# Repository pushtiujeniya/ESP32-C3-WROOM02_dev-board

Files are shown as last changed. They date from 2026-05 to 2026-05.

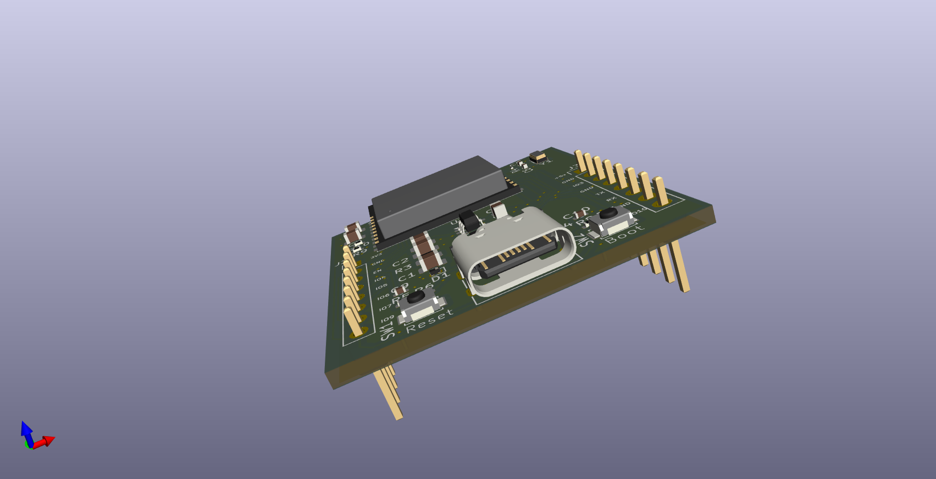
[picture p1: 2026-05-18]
3D view/3D_ USB view.png

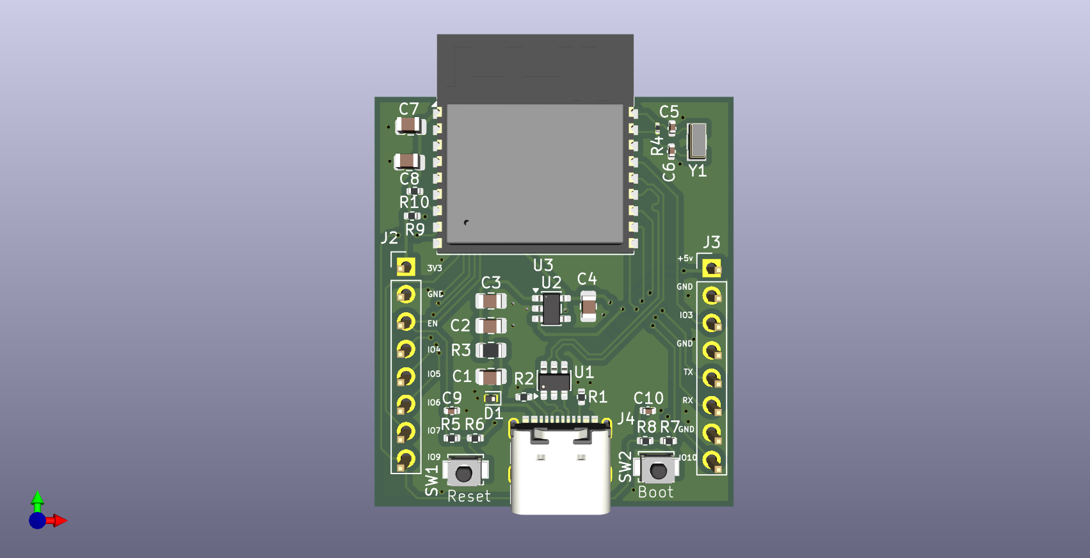
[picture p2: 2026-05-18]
3D view/3D_ Top view.png

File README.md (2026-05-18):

# ESP32-C3-WROOM-02 Development Board

## Overview

This project is a custom 2-layer development board designed around the ESP32-C3-WROOM-02 Wi‑Fi + Bluetooth MCU module. The board includes USB Type‑C power input, onboard 3.3V regulation, boot/reset circuitry, GPIO breakout headers, and USB protection components.

## Features

* ESP32-C3-WROOM-02 module
* USB Type‑C interface
* Onboard 3.3V regulator
* Boot and reset buttons
* GPIO breakout headers
* USB ESD protection
* Power indicator LED
* 2-layer PCB design

## Applications

* IoT devices
* Embedded development
* Sensor interfacing
* Wireless communication projects
* Learning and prototyping

## Hardware Included

* ESP32-C3-WROOM-02 MCU module
* USB Type‑C connector
* Voltage regulator
* Decoupling capacitors
* ESD protection devices
* Boot/reset circuitry
* GPIO expansion headers

## Notes

* Operates on 3.3V logic
* Powered through USB Type‑C
* Suitable for firmware development using ESP-IDF or Arduino framework

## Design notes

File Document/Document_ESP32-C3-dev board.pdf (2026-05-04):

ESP32-C3-WROOM02 mini module development board

Main Hardware components

- USB 2.0 type C connector
- LDO (AP211K-3.3) which converts 3.3V required voltage for power on the MCU
- Boot button- to flash the firmware or to go into bootloader mode to flash the firmware
- Reset button- to reset the MCU manually
- External 32.768KHZ crystal oscillator
- Pin header for JTAG/UART
- ESD protection circuit from USB to LDO to protect the USB data line(USBLC6-2SC6)

Working flow of the board
- USB type C connector will be the main power input to the board
- From USB we get the 5 V DC voltage which goes to LDO which convert the 3.3V with protection circuit in between from 5 V to 3.3V
- 3.3V power rail from LDO will direct goes to the power on to ESP32-C3 mini
- Boot button at (GPIO8) is used to put MCU into programming mode
- Reset button (at EN pin) allows to reset the MCU manually
- External crystal 32.768khz provide stable clock cycle
- Pin header for UART/JTAG for debugging mode

USB C connector

- vbus
Power pin got the 5V power from the PC

Cc1 and cc2 pins
Pins used to detect the connection , cable orientation
By keeping pull up or pull down resistors connection at cc1 nad cc2 the cable detected and decided whether i have to act as host ( to drive the power to the board) or device ( to ask for power from the host)

It is configuration channel pins
This pins tell the host that cable is inserted
So usb plug detection is done by this
By default USB standards the USB type C connecter will get the 5V DC from the host (pc or charger)

How can type c verify the orientation of cable detect
In normal insertion cable connects c1
Cc2 not detected

But in flipped insertion

C2- not detected
C1- cable connects

Only 1 cc1 lines is physically connected at a time other one is floating Host (PC or charger ) checks voltage on both pins
When host checks voltage on both pins
If voltage available on c1= normal orientation
If voltage available on c2= flipped orientation

SBU1 and SBU2 pins
Sideband pins
In normal USB2.0 communication this pins are not used and left unconnected
This pin used when USB c used as headphone jack means when this pins carry some audio data

USBLC6-2SC6

This is ESD protection IC used to protect the data lines from USB connector coming It will protect the data lines from static electricity and voltage spikes

In this 1 and 3 pins are input pins
4 and 5 are output pins
5= vbus
2=gnd

So at 4 and 6 pins getting output USB D+ and USB D- data

LDO (AP2112K-3.3)

This will convert the 5 V which is got from the USB connector and convert it into 3.3v to power on the MCU
As ESP32-C3 module
Ideal current consumption is 20 to 40mA
And active wifi current consumption=300 to 400mA
So decided to have some extra current capacity carrying LDO AP2112K-3.3 this is 600mA current carrying capacity of LDO AMS1117-3.3 the dropout voltage =1.3v max
AP2112K-3.3 the dropout voltage is 400mV
So power loss/heat would be less in AP2112K-3.3
Also it has fast response to sudden current peak

MCU
ESP32-C3-WROOM02

VBUS
MCU operates at 3.3V
3.3V rail is the main power supply provider rail Decoupling capacitor at power line= 10uf and 0.1uf

10uF will filter out low frequency noise
0.1uF will filter out high frequency noise

EPAD pin
This pin should connect with ground pin for good thermal performance

Crystal
MCU has internal crystal oscillator of 40MHz crystal
And internal crystal oscillator (32.768khz) can be connected with IO0 and IO1

EN pin at pin 2
This pin is used to manually boot the MCU for flashing the firmware or go into bootloader mode

To enter into bootloader mode
Hold boot button (GPIO 9 low)
Press reset (EN pin low)
Release reset
Release boot

So manually push button switch is connected to with this pin
And by default in nominal mode the EN pin is high by pull up resistor
and when switch is pressed it connects with gnd and goes to low
When the switch is pressed the EN pin goes low immediately and when released the switch EN pin again goes high so this fast switching can create noise in EN pin
So to remove that noise rise delay is added
By t=RC
There should be resistor and capacitor in series with the other end of the switch
This RC combination circuit is called debouncing circuit
Also one pull up resistor is connected to the switch to keep the by default switch in high mode When it is pressed it goes to gnd

USB pins in MCU
IO18 for USB-D-IO19 for USB-D+

From USB this data lines are connected to MCU io18 and io19 poins
In between from USB to MCU path there is one ESD protection diode which is USBLC6-CS and output of this diode is goes into MCU data lines pins

Strapping pins
This pins are used to decide MCU operating mode (normal flashing mode or bootloader mode) GPIO2, GPIO8, GPIO9 are for strapping pins
While power on time the MCU checks this strapping pins at that time if pins are high then MCU run into normal mode so it will run the flashed firmware
But if GPIO8, GPIO9 are low= run into bootloader mode
To keep the strapping pins high for normal mode 10kohm pull up resistors are required

TX, RX pins of the MCU

IO20 and IO21 are the TX and RX pins IO20- RX
IO21-TX

Crystal connection with MCU
There are 2 load capacitors required with external crystal to stabilize the oscillation And one resistor to help oscillations start easily

Load capacitors are used to stabilize the oscillations.
Load capacitors values are mentioned in the datasheet of crystal oscillator

COMPONENT SELECTION and TECHNICAL SPECIFICATION

USB section

At cc1 and cc2 pins there is 5.1kohm pull down resistors
This pull down resistors used to tell the host that i am the device give me power through USB connector
5.1kohm value this is mentioned in the type c specification

Here why pull down resistors connected what if i connect pull up resistors
If pull up resistors connected at cc1 and cc1 it mean usb will drive the power (it would become host)
So in case when you want to give the power to the board by USB supply then connect pull up resistors at cc1 and cc2 pins

By pull down resistors connection at cc1 and cc2 = i am the device give me the power supply Asking for power from the host

LDO decoupling capacitors

At vin and vout pin there is decoupling capacitors needed to remove high frequency noise and low frequency noise
Here 4.7uF used
1uf to 4.7uf value range= to remove low frequency noise
0.1uf= to remove high frequency noise

In datasheet 1uF is mentioned for vin and vout
We can use 4.7uf also

BOOT SWITCH AND RESET SWITCH
As the by default the boot and reset switch need to keep at high state so that whenever user want to enter into boot mode by pressing the switch you can do it

So pull up resistors required to keep the switch by default in high state
Note: should keep low value for pull up resistors in the switch so that by weak enough the pin easily goes to low when button is pressed

Here 10kohm is enough to keep the line low

Debounce circuit ( R and C) value at switch R=10kohm
C=0.1uf

t=RC= 10kohm x 0.1uf =1ms
This will add 1ms of time delay in rise of the EN or reset pin because if it goes immediately high after pressing the switch then noise might be added
This combination of the RC at switch is called debounce circuit

WHY EXTERNAL CRYSTALS NEEDED WHEN MCU HAS INTERNAL CRYSTAL ENOUGH

When internal crystal lacks at stability, precision then external l crystal is used

Both load capacitors have same value at crystal connection
And one resistor in parallel

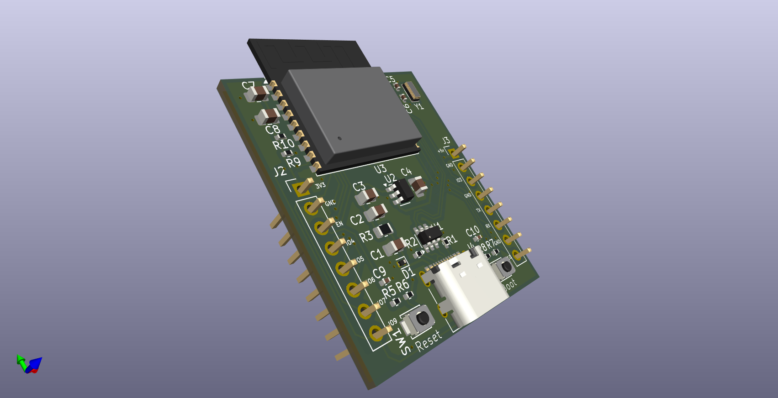
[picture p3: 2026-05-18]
3D view/3D_side view.png

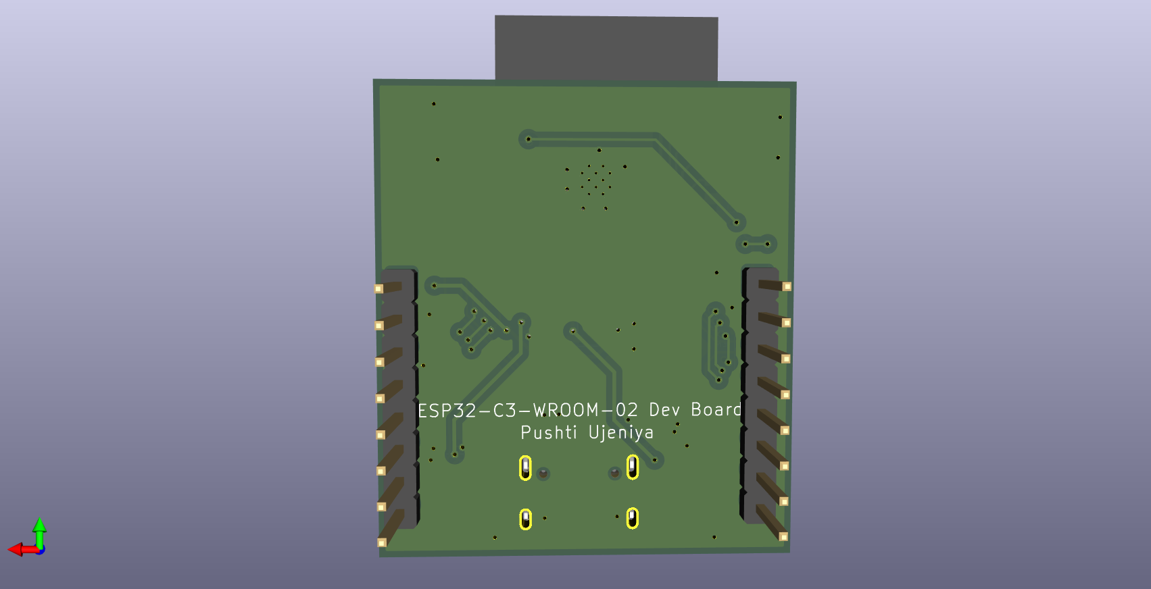
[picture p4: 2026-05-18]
3D view/3D_Bottom view.png

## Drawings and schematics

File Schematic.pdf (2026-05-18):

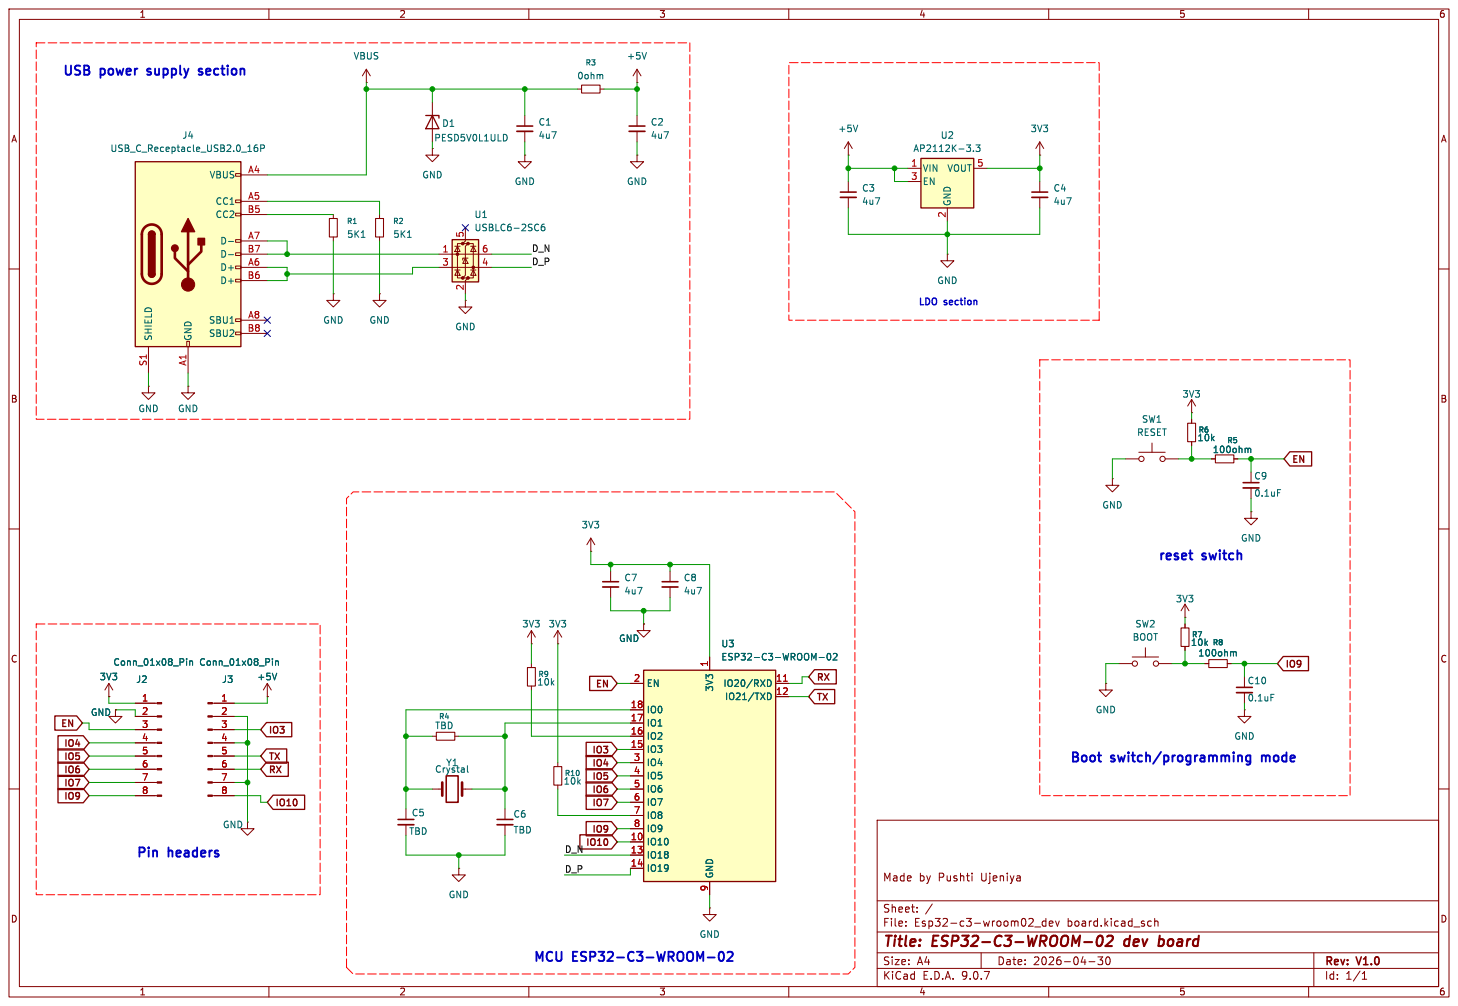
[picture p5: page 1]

USB power supply section

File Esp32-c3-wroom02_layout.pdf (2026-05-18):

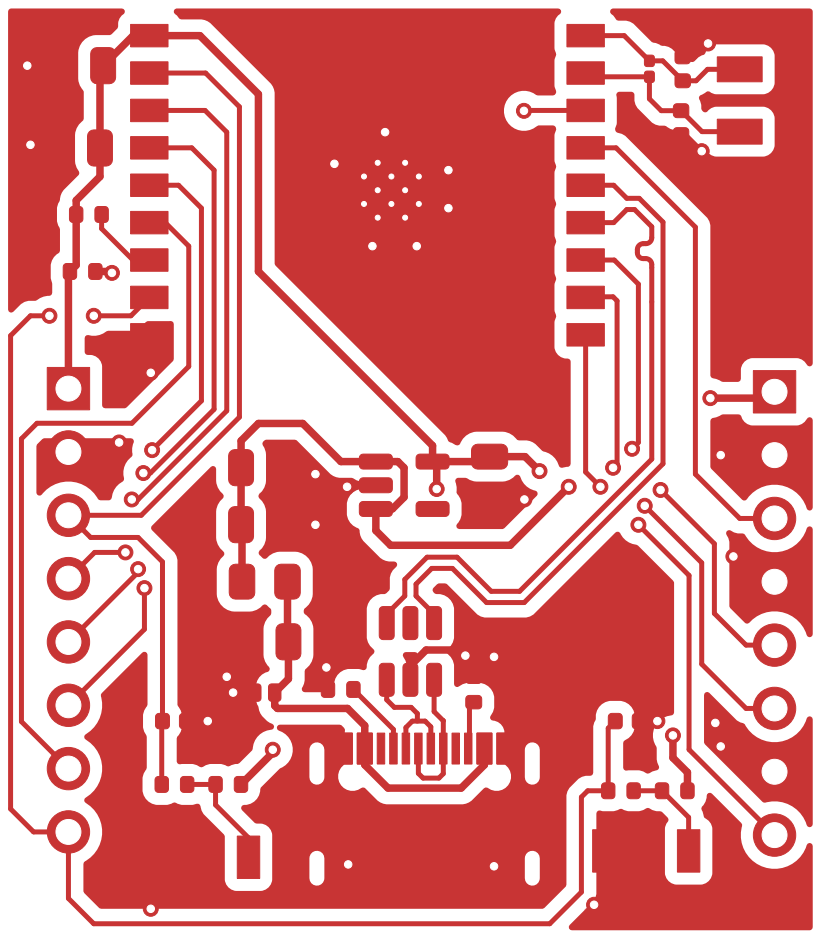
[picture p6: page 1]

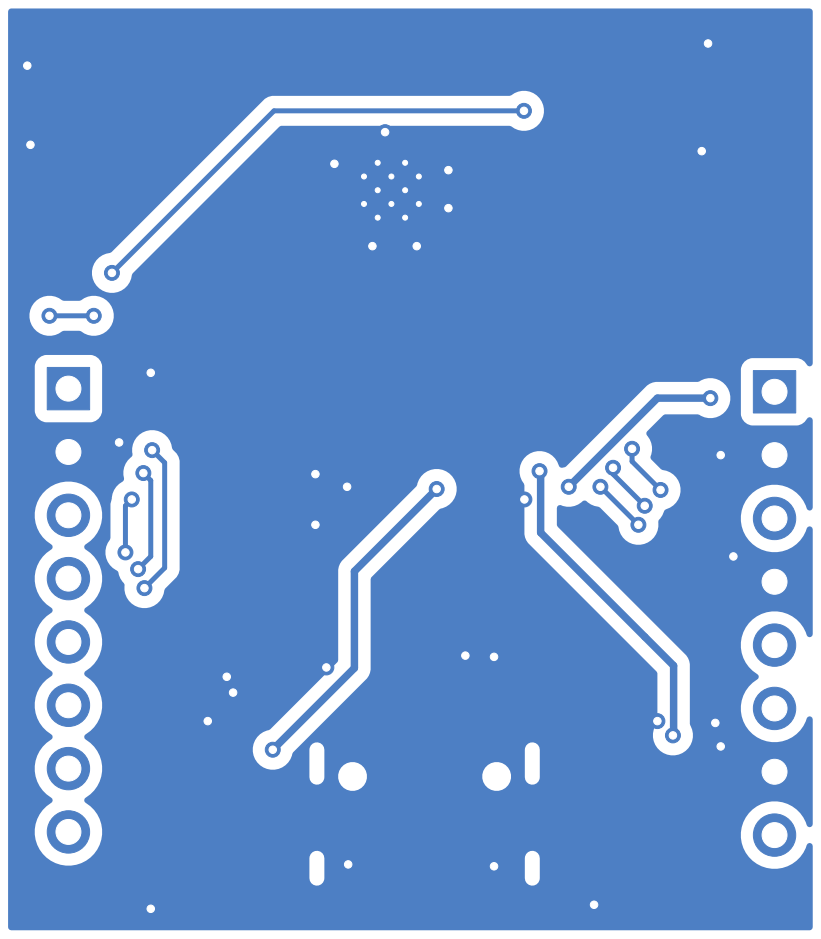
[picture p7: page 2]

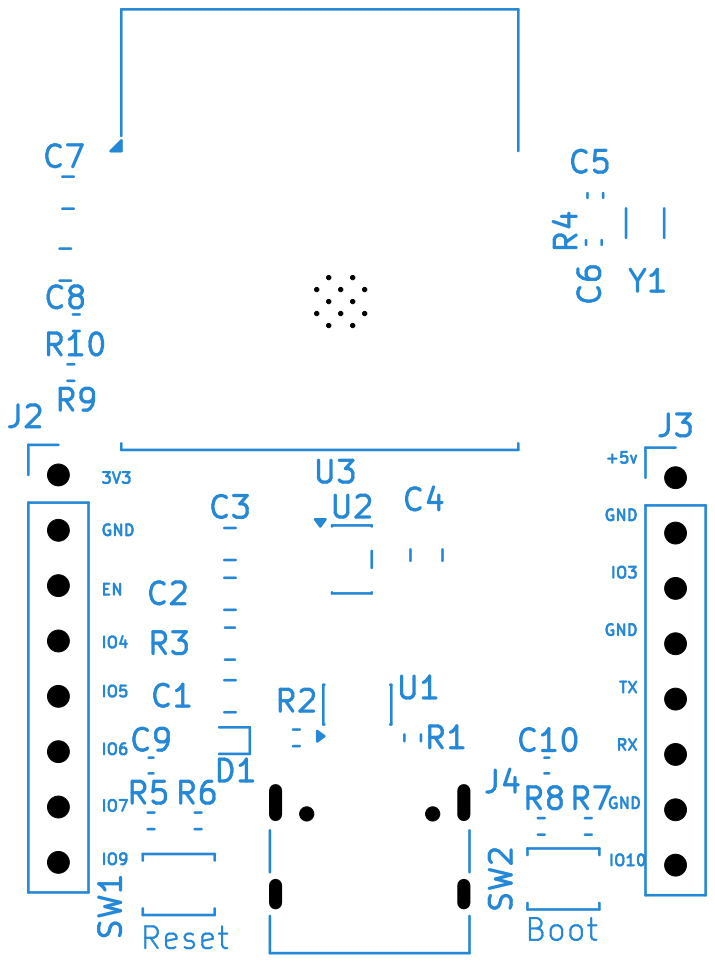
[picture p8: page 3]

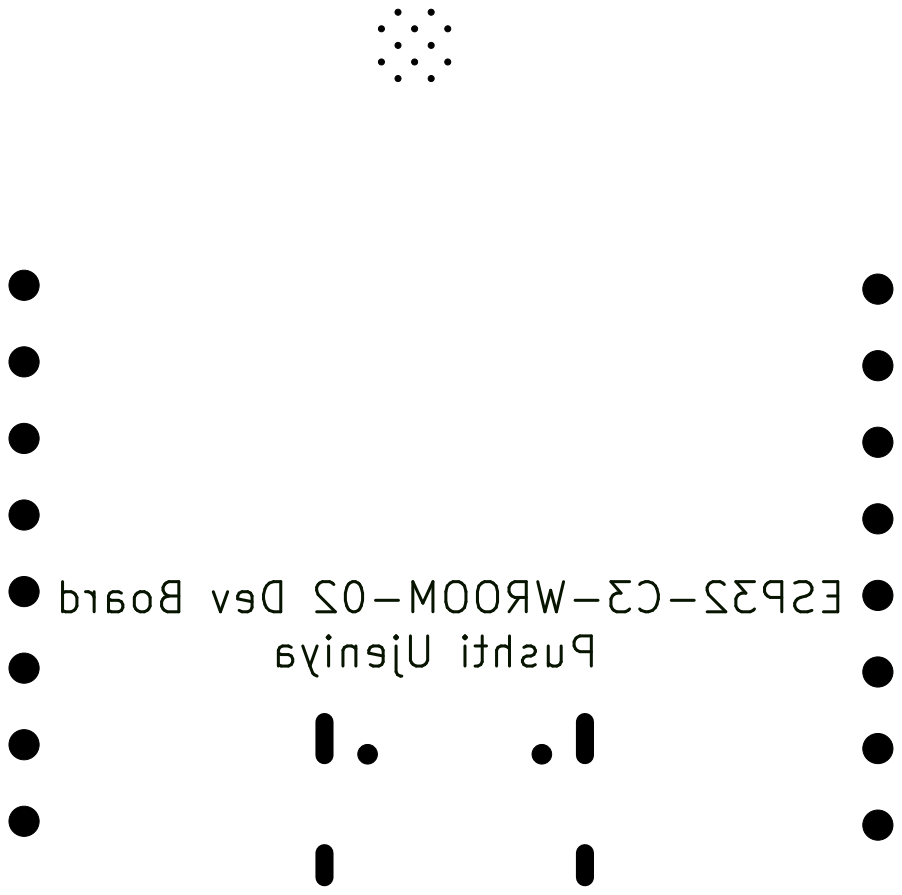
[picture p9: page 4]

Ujeniya Pushti Board Dev ESP32-C3-WROOM-02

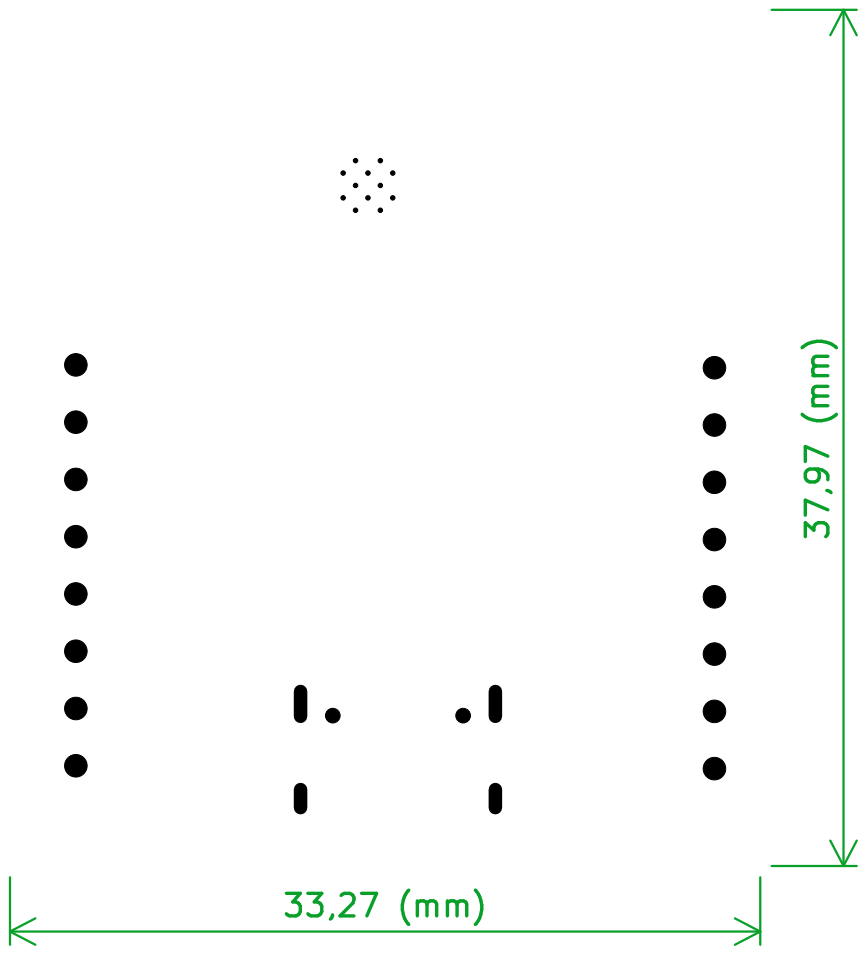
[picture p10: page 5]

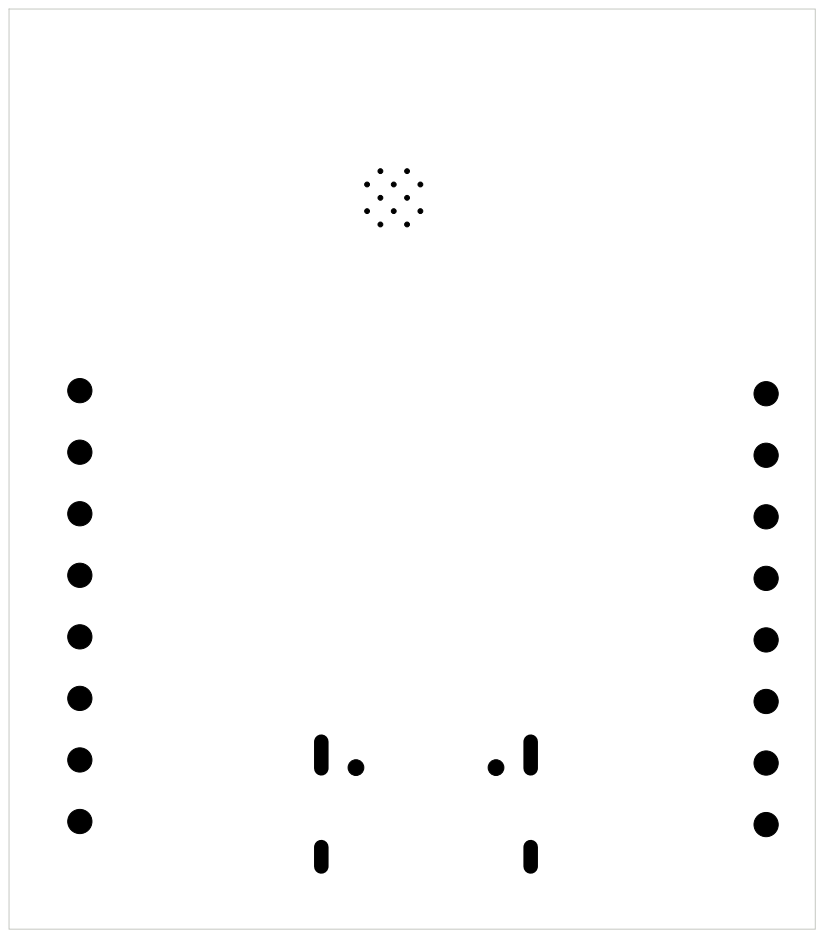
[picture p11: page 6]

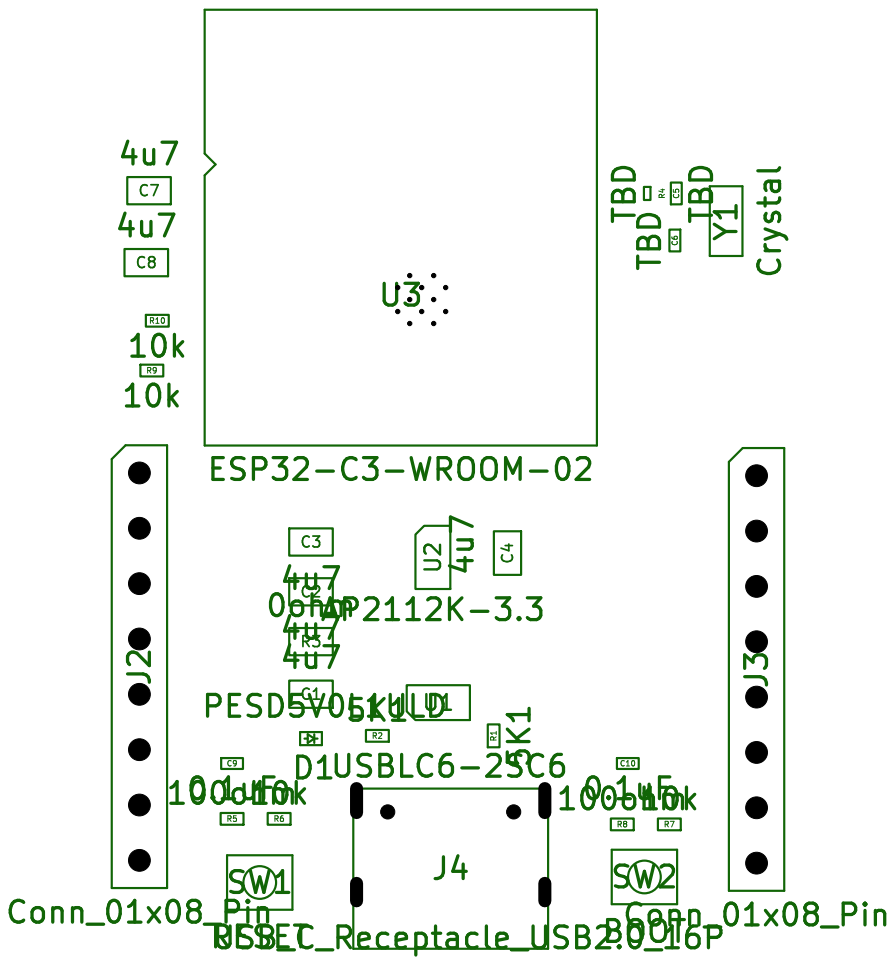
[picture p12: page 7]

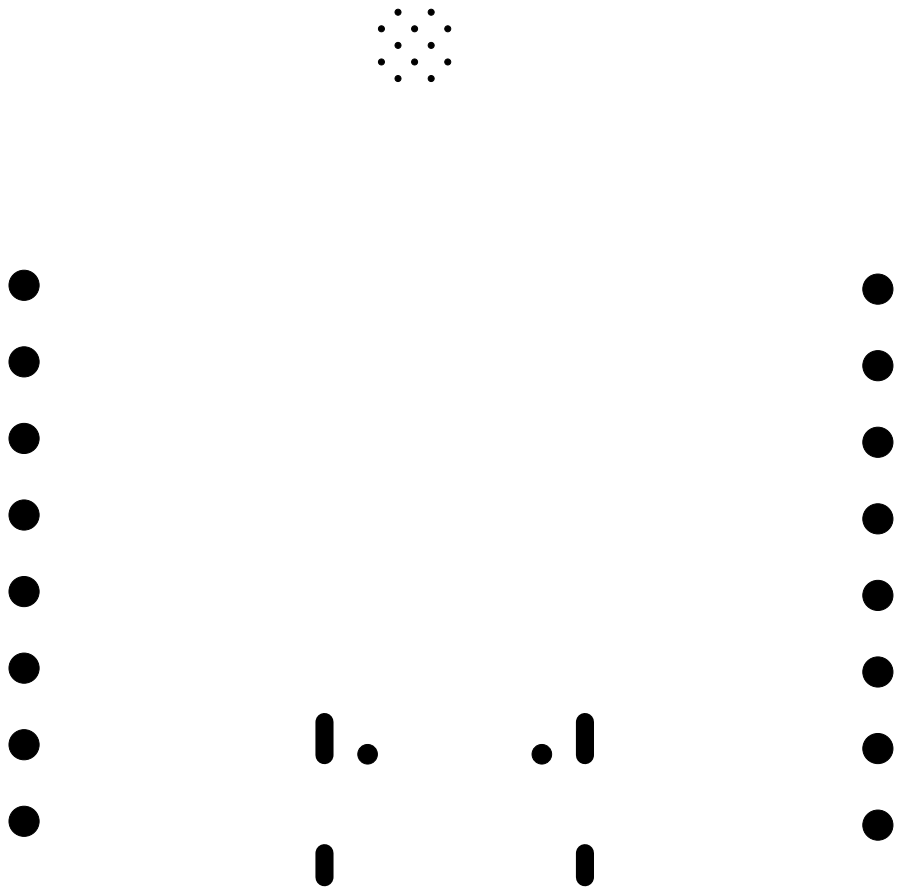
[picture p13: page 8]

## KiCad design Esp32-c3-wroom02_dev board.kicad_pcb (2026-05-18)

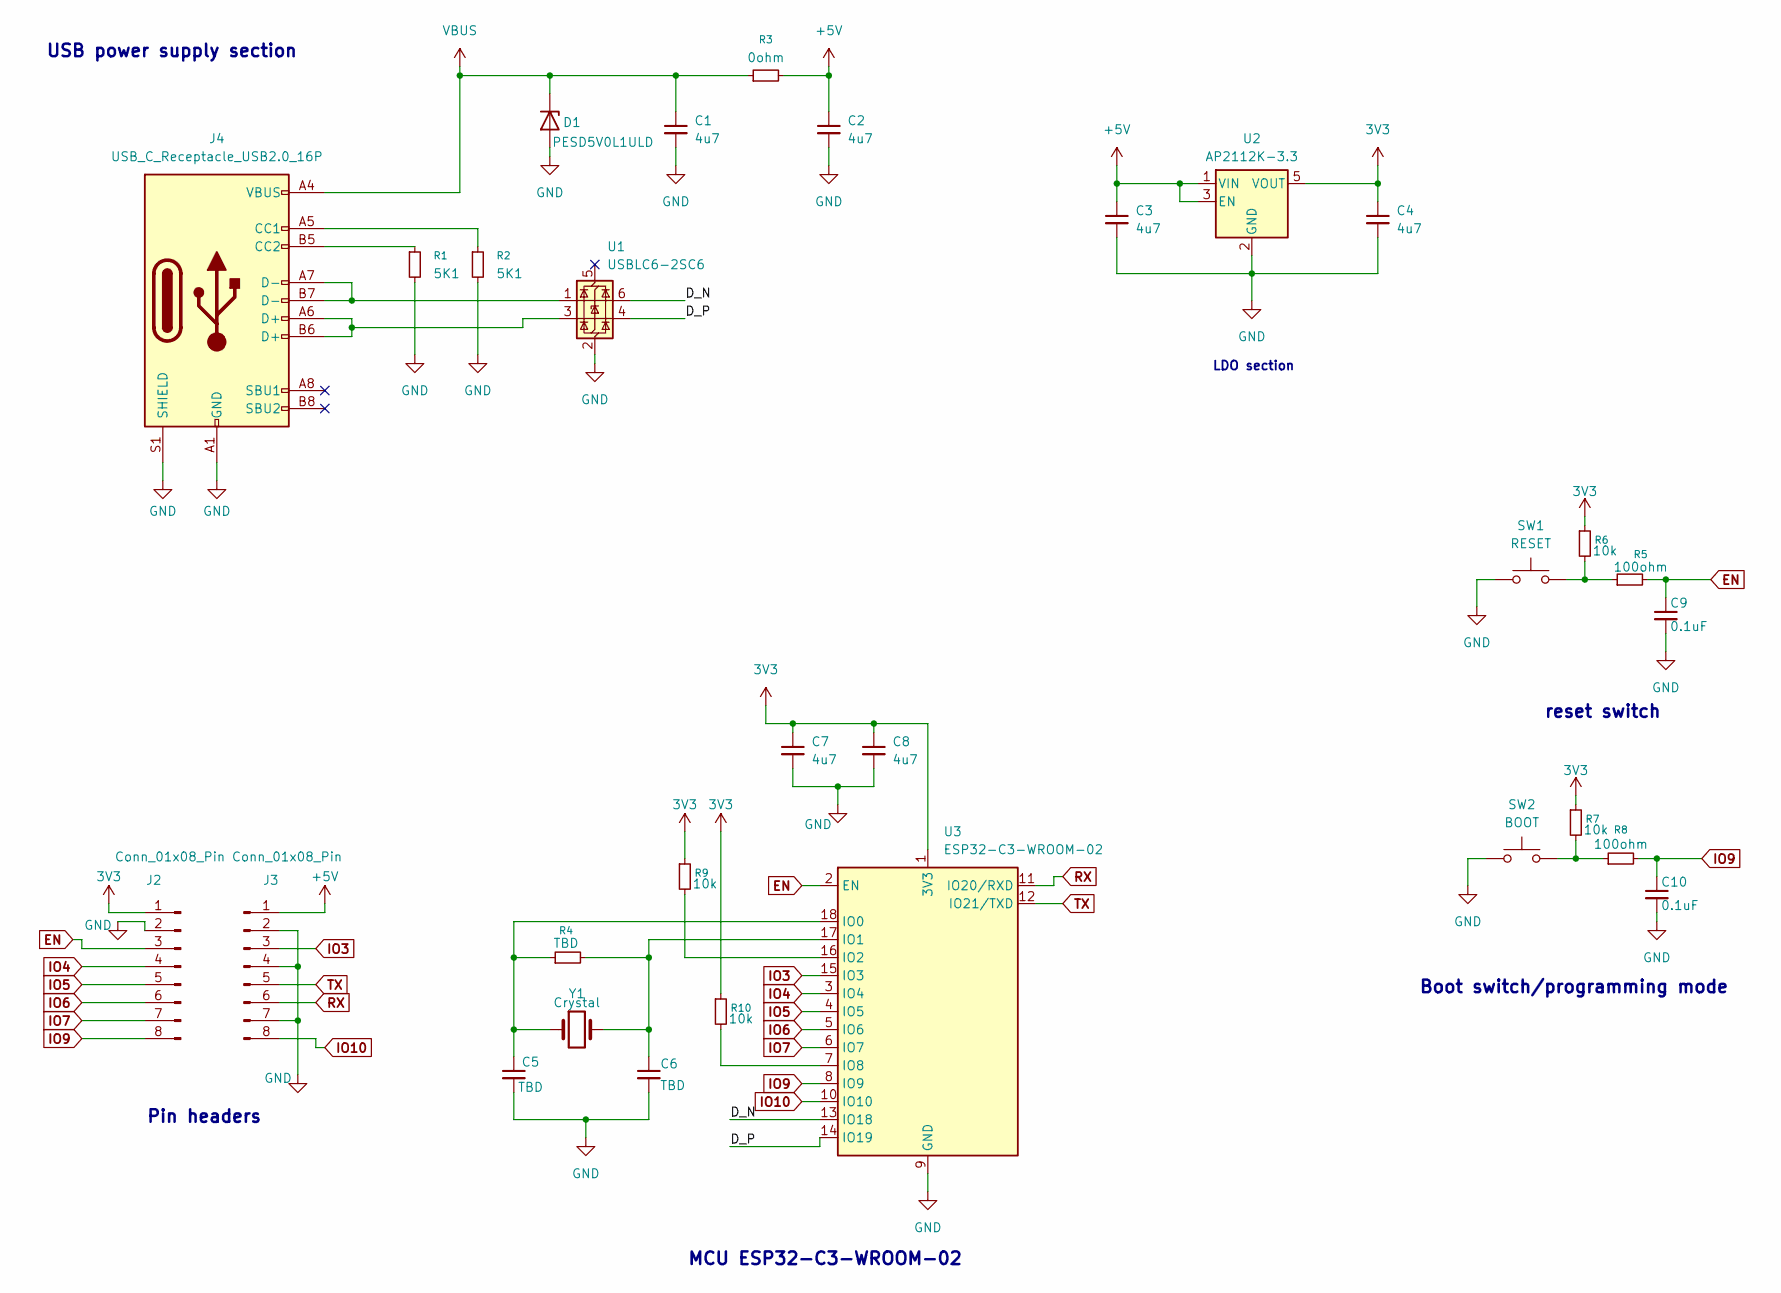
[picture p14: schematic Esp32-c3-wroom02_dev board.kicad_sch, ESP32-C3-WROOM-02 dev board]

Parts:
C1, C2, C3, C4, C7, C8: 4u7; C_0805_2012Metric
C5, C6: TBD; C_0402_1005Metric
C9, C10: 0.1uF; C_0402_1005Metric
D1: PESD5V0L1ULD; D_SOD-882D
J2, J3: Conn_01x08_Pin; PinHeader_1x08_P2.54mm_Vertical
J4: USB_C_Receptacle_USB2.0_16P; USB_C_Receptacle_G-Switch_GT-USB-7010ASV
R1, R2: 5K1; R_0402_1005Metric
R3: 0ohm; R_0805_2012Metric
R4: TBD; R_0201_0603Metric
R5, R8: 100ohm; R_0402_1005Metric
R6, R7, R9, R10: 10k; R_0402_1005Metric
SW1: RESET; SW_SPST_B3U-1000P
SW2: BOOT; SW_SPST_B3U-1000P
U1: USBLC6-2SC6; SOT-23-6
U2: AP2112K-3.3; SOT-23-5
U3: ESP32-C3-WROOM-02
Y1: Crystal; Crystal_SMD_3215-2Pin_3.2x1.5mm

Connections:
3V3: C4.1, C7.1, C8.1, J2.1, R6.1, R7.1, R9.1, R10.1, U2.5 (VOUT), U3.1 (3V3)
+5V: C2.1, C3.1, J3.1, R3.2, U2.1 (VIN), U2.3 (EN)
/D_N: U1.6 (I/O1), U3.13 (IO18)
/D_P: U1.4 (I/O2), U3.14 (IO19)
EN: C9.1, J2.3, R5.2, U3.2 (EN)
GND: C1.2, C2.2, C3.2, C4.2, C5.2, C6.2, C7.2, C8.2, C9.2, C10.2, D1.2 (A), J2.2, J3.2, J3.4, J3.7, J4.A1 (GND), J4.A12 (GND), J4.B1 (GND), J4.B12 (GND), J4.S1 (SHIELD), R1.2, R2.2, SW1.1, SW2.1, U1.2 (GND), U2.2 (GND), U3.9 (GND), U3.19 (GND)
IO3: J3.3, U3.15 (IO3)
IO4: J2.4, U3.3 (IO4)
IO5: J2.5, U3.4 (IO5)
IO6: J2.6, U3.5 (IO6)
IO7: J2.7, U3.6 (IO7)
IO9: C10.1, J2.8, R8.2, U3.8 (IO9)
IO10: J3.8, U3.10 (IO10)
unnamed: J4.A5 (CC1), R2.1
unnamed: J4.B5 (CC2), R1.1
unnamed: J4.A6 (D+), J4.B6 (D+), U1.3 (I/O2)
unnamed: J4.A7 (D-), J4.B7 (D-), U1.1 (I/O1)
unnamed: R5.1, R6.2, SW1.2
unnamed: R7.2, R8.1, SW2.2
unnamed: C5.1, R4.1, U3.18 (IO0), Y1.1
unnamed: C6.1, R4.2, U3.17 (IO1), Y1.2
unnamed: R9.2, U3.16 (IO2)
unnamed: R10.2, U3.7 (IO8)
RX: J3.6, U3.11 (IO20/RXD)
TX: J3.5, U3.12 (IO21/TXD)
VBUS: C1.1, D1.1 (K), J4.A4 (VBUS), J4.A9 (VBUS), J4.B4 (VBUS), J4.B9 (VBUS), R3.1

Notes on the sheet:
Pin headers
Boot switch/programming mode
reset switch
LDO section
USB power supply section
MCU ESP32-C3-WROOM-02

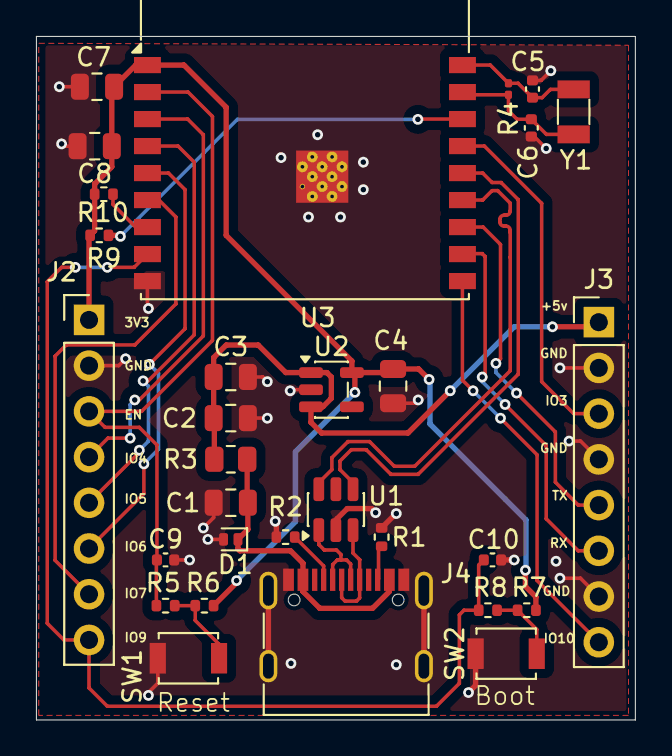
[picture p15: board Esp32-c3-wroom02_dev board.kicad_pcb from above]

Board: 2 copper layers, 33.3 x 38.0 mm, 30 parts (0 on the bottom side), 26 nets.

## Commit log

2026-05-18 schematic file added
    [Esp32-c3-wroom02_dev board.kicad_sch]
2026-05-18 schematic pdf added
2026-05-18 layout file added
    [Esp32-c3-wroom02_dev board.kicad_pcb]
2026-05-18 Add README for ESP32-C3-WROOM-02 development board
    This README provides an overview of the ESP32-C3-WROOM-02 development board, detailing its features, applications, included hardware, and operational notes.
